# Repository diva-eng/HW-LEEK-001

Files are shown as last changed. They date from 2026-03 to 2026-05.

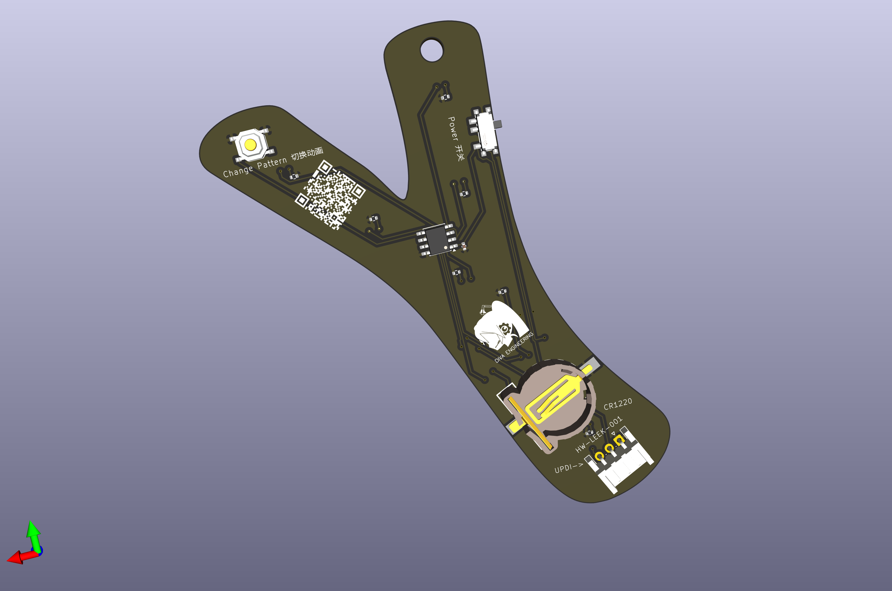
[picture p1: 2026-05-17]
HW-LEEK-001.png

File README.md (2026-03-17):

# Leek PCB Keychain

A small-form-factor PCB keychain shaped like Hatsune Miku's iconic leek, designed as concert swag for Magical Mirai. Features green LEDs at the tip, white LEDs at the base, and multiple user-selectable lighting patterns driven by an ATtiny402.

---

## Features

- Leek-shaped PCB outline with keychain mounting hole
- 5x green LEDs (leek tip) + 2x white LEDs (base)
- 4 lighting patterns selectable via tactile button
- SPDT slide switch for hard power on/off
- CR1220 coin cell powered (~16 hours active runtime)
- Fully assembled by JLCPCB (SMT + THT)

## Hardware

| Comment | Designator | Footprint | LCSC | Quantity |
|---|---|---|---|---|
| ATtiny402-SS | U1 | SOIC-8_3.9x4.9mm_P1.27mm | C2053235 | 1 |
| Battery_Cell | BT1 | BAT-SMD_MY-1220-03 | C964818 | 1 |
| C | C1 | C_0402_1005Metric | C1525 | 1 |
| LED | D6,D7 | LED_0603_1608Metric | C189306 | 2 |
| LED | D4,D5 | LED_0603_1608Metric | C5246833 | 2 |
| LED | D1,D2,D3 | LED_0805_2012Metric | C5355441 | 3 |
| R | R6,R7 | R_0402_1005Metric | C25076 | 2 |
| R | R1,R2,R3,R4,R5 | R_0402_1005Metric | C25104 | 5 |
| ~ | SW3 | SW-TH_K3-1296S-E1 | C128955 | 1 |
| ~ | SW4 | SW-SMD_4P-L5.1-W5.1-P3.70-LS6.5-TL_H1.5 | C318884 | 1 |
| Conn_01x03_Pin | J1 | JST_EH_S3B-EH_1x03_P2.50mm_Horizontal |  | 1 |

See the full design document for complete BOM, resistor values, and wiring details.

## Firmware

Written in Arduino IDE using [megaTinyCore](https://github.com/SpenceKonde/megaTinyCore).

**Board manager URL:**
```
http://drazzy.com/package_drazzy.com_index.json
```

**Board settings:**
- Board: `ATtiny402`
- Clock: Internal 32kHz
- Programmer: SerialUPDI or Microchip SNAP

## Programming

The ATtiny402 is programmed via UPDI using 3 pads on the PCB edge (GND, VCC, UPDI). The cheapest programmer is a CH340 USB-serial adapter with a 1kΩ resistor:

```
USB-Serial TX ── 1kΩ ── UPDI pad
USB-Serial RX ──────── UPDI pad
GND ────────────────── GND pad
```

## LED Patterns

| # | Name | Description |
|---|---|---|
| 1 | Slow Pulse | Both LEDs breathe in and out together |
| 2 | Alternate | Green and white flash in turns |
| 3 | Chase | Green → white → both → off, repeat |
| 4 | Heartbeat | Double-flash then long pause |

Press the pattern button to cycle. The selected pattern is saved to EEPROM and restored on next power-on.

## License

MIT — see [LICENSE](LICENSE)

---

*A [Diva Engineering](https://github.com/diva-eng) project.*

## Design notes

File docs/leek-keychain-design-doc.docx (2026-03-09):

DIVA ENGINEERING

Leek PCB Keychain

Hardware Design Document | Magical Mirai Concert Swag

Document ID | HW-LEEK-001
Version | 1.0
Date | March 2026
Author | Diva Engineering
GitHub | https://github.com/diva-eng
Status | Draft — Ready for PCB Design

# 1. Project Overview

The Leek PCB Keychain is a small-form-factor PCB designed to be distributed as concert swag at Magical Mirai events. Shaped like Hatsune Miku's iconic leek prop, it features green LEDs at the tip and white LEDs at the base, driven by a microcontroller with multiple user-selectable lighting patterns. The device is powered by a coin cell battery and includes a power switch and a pattern selection button.

## 1.1 Design Goals

- Leek-shaped PCB outline, keychain form factor
- Green LEDs at the tip (leek top), white LEDs at the base (cut end)
- 4 stored lighting patterns, selectable via a tactile button
- SPDT slide switch for hard power on/off
- CR1220 coin cell power — small enough for keychain use
- Fully assembled by JLCPCB (SMT + THT)
- Firmware written in Arduino IDE using megaTinyCore

## 1.2 Project References

- Related project: BOKAKA smart PCB card (https://github.com/diva-eng/BOKAKA)
- Related project: diva-card RP2040 dev board (https://github.com/diva-eng/diva-card)
- Org GitHub: https://github.com/diva-eng

# 2. Hardware Specification

## 2.1 Microcontroller — ATtiny402

The ATtiny402 in SOT-23-8 is selected as the MCU. It is a Microchip AVR 0-series device with sufficient I/O for this application, native PWM for LED fading, and extremely low sleep current. It is supported by JLCPCB assembly and programmable via UPDI using Arduino IDE with megaTinyCore.

Parameter | Value
Package | SOT-23-8
Flash | 4KB
SRAM | 256 bytes
EEPROM | 128 bytes
Operating Voltage | 1.8V – 5.5V
Active Current @ 1MHz | ~0.8mA
Active Current @ 32kHz | ~100µA
Power-down Sleep | ~0.1µA
PWM channels | 2 (TCA0)
Programming Interface | UPDI (single wire)
LCSC Part | C440337

## 2.2 Pin Allocation

Physical Pin | Port | Arduino Pin (megaTinyCore) | Function
1 | VCC | — | Power supply
2 | PA6 | 1 | Green LED group output
3 | PA7 | 2 | White LED group output
4 | PA1 | 4 | UPDI programming
5 | PA2 | 3 | Pattern select button input
6 | PA3 | — | Spare / future use
7 | GND | — | Ground
8 | PA0 | — | RESET (not used)

## 2.3 Power — CR1220 Coin Cell

The CR1220 is chosen as the primary power source. It offers a good balance of small physical size and sufficient capacity for concert use. Since the device includes a hard power switch, battery life in active use is the only relevant metric.

Parameter | Value
Chemistry | Lithium manganese dioxide
Diameter | 12mm
Thickness | 2.0mm
Nominal Voltage | 3V
Capacity | ~35mAh
Estimated active runtime | ~16 hours @ 2.1mA total draw
Concerts covered | 5+ at 3 hours each
LCSC Holder Part | C70377

## 2.4 LED Specification

Green LEDs (Leek Tip — 4x)

Parameter | Value
Color | Green
Package | 0402 SMD
Forward Voltage (Vf) | ~2.1 – 2.3V
Target current per LED | 2mA
Series resistor | 390Ω
LCSC Part | C2297 (verify Vf in datasheet)
Qty | 4

White LEDs (Leek Base — 2x)

White LEDs have a forward voltage near the coin cell supply voltage. Use low-Vf white LEDs (Vf ≤ 2.8V) to ensure reliable operation.

Parameter | Value
Color | White (low Vf)
Package | 0402 SMD
Forward Voltage (Vf) | ≤ 2.8V (verify before ordering)
Target current per LED | 2mA
Series resistor | 68Ω
LCSC Part | C2290 (verify Vf ≤ 2.8V in datasheet)
Qty | 2

## 2.5 Passive Components

Ref | Component | Value | Package | LCSC Part | Qty
C1 | Bypass capacitor | 100nF 10V | 0402 | C307331 | 1
R1–R4 | Green LED resistors | 390Ω | 0402 | C105872 | 4
R5–R6 | White LED resistors | 68Ω | 0402 | C105854 | 2

## 2.6 Switches

Ref | Component | Type | Package | LCSC Part | Qty
SW1 | Power switch | SPDT slide | SMD | C431540 | 1
SW2 | Pattern select | Tactile push button | 3x4mm SMD | C455280 | 1

# 3. Full Bill of Materials

All parts are sourced from LCSC and suitable for JLCPCB SMT + THT assembly. Verify all LCSC part numbers and datasheets before placing the order, especially LED Vf values.

Ref | Component | Value / Part | Package | LCSC Part | Qty | Assembly
U1 | MCU | ATtiny402 | SOT-23-8 | C440337 | 1 | SMT
C1 | Bypass Cap | 100nF 10V | 0402 | C307331 | 1 | SMT
R1–R4 | Resistor | 390Ω | 0402 | C105872 | 4 | SMT
R5–R6 | Resistor | 68Ω | 0402 | C105854 | 2 | SMT
D1–D4 | Green LED | Low Vf Green | 0402 | C2297 | 4 | SMT
D5–D6 | White LED | Low Vf White ≤2.8V | 0402 | C2290 | 2 | SMT
SW1 | Power Switch | SPDT Slide | SMD | C431540 | 1 | SMT
SW2 | Pattern Button | Tactile 3x4mm | SMD | C455280 | 1 | SMT
BT1 | Battery Holder | CR1220 | THT | C70377 | 1 | THT
J1 | UPDI Header | 3-pin 2.54mm | THT | C49257 | 1 | THT

Note: J1 (UPDI header) can be replaced with 3 exposed edge pads for pogo-pin programming after the first batch is validated, removing the need for a physical header.

# 4. Circuit Description

## 4.1 Power Path

The CR1220 positive terminal connects through SW1 (SPDT slide switch) to the VCC rail. The negative terminal connects directly to GND. C1 (100nF ceramic) is placed as close as possible to the ATtiny402 VCC pin to decouple supply noise.

CR1220(+) ── SW1 (slide) ── VCC rail ── ATtiny402 VCC

CR1220(-) ──────────────── GND

C1 (100nF) between VCC and GND, placed near U1

## 4.2 LED Wiring

Each LED has an individual series resistor. All LEDs in a group share the same MCU output pin. Cathodes connect to GND.

ATtiny402 PA6 ──┬── R1 (390Ω) ── D1 (Green) ── GND

├── R2 (390Ω) ── D2 (Green) ── GND

├── R3 (390Ω) ── D3 (Green) ── GND

└── R4 (390Ω) ── D4 (Green) ── GND

ATtiny402 PA7 ──┬── R5 (68Ω) ── D5 (White) ── GND

└── R6 (68Ω) ── D6 (White) ── GND

## 4.3 Pattern Select Button

SW2 connects PA2 to GND. The ATtiny402 internal pullup is enabled in firmware, so no external pullup resistor is required. Button press pulls PA2 low, triggering a pattern change with software debounce.

ATtiny402 PA2 ── SW2 ── GND

(Internal pullup enabled in firmware — no external resistor needed)

## 4.4 UPDI Programming Header

J1 is a 3-pin 2.54mm THT header exposing GND, VCC, and UPDI (PA1) for in-system programming. Place on the board edge for pogo-pin access.

J1 Pin 1: GND

J1 Pin 2: VCC

J1 Pin 3: UPDI (PA1)

# 5. LED Patterns

Four patterns are stored in firmware. The active pattern is saved to EEPROM so it persists across power cycles. Patterns are cycled by pressing SW2 (short press).

# | Name | Green (PA6) | White (PA7) | Description

1 | Slow Pulse | PWM breathe | PWM breathe | Both LEDs fade in and out together slowly
2 | Alternate | Flash on | Flash off (inverse) | Green and white take turns flashing
3 | Chase | On → Off → Both | Off → On → Both | Sequential: green, white, both, off
4 | Heartbeat | Double-flash + pause | Double-flash + pause | Quick double-flash then a long pause

PWM fading uses the ATtiny402 hardware TCA0 peripheral. No bit-banging is required. The 32kHz internal oscillator is sufficient for smooth visible fading.

# 6. Firmware

## 6.1 Toolchain

Tool | Version / Details
IDE | Arduino IDE 2.x
Board Package | megaTinyCore by Spence Konde
Board Manager URL | http://drazzy.com/package_drazzy.com_index.json
Board Selection | ATtiny402
Clock | Internal 32kHz (sufficient for LED PWM)
Programmer | SerialUPDI or Microchip SNAP

## 6.2 Firmware Structure

#include <Arduino.h>

#include <EEPROM.h>

#define PIN_GREEN PIN_PA6

#define PIN_WHITE PIN_PA7

#define PIN_BUTTON PIN_PA2

#define NUM_PATTERNS 4

uint8_t currentPattern = 0;

void setup() {

pinMode(PIN_GREEN, OUTPUT);

pinMode(PIN_WHITE, OUTPUT);

pinMode(PIN_BUTTON, INPUT_PULLUP);

currentPattern = EEPROM.read(0) % NUM_PATTERNS;

}

void loop() {

if (digitalRead(PIN_BUTTON) == LOW) {

delay(50); // debounce

if (digitalRead(PIN_BUTTON) == LOW) {

currentPattern = (currentPattern + 1) % NUM_PATTERNS;

EEPROM.update(0, currentPattern);

while (digitalRead(PIN_BUTTON) == LOW);

}

}

switch (currentPattern) {

case 0: patternSlowPulse(); break;

case 1: patternAlternate(); break;

case 2: patternChase(); break;

case 3: patternHeartbeat(); break;

}

}

## 6.3 EEPROM Usage

The last active pattern index is stored at EEPROM address 0 using EEPROM.update() (only writes if value changed, preserving EEPROM write cycle life). On boot, this value is read and restored.

# 7. Programming Setup

## 7.1 SerialUPDI Programmer (Recommended)

A CH340 or CP2102 USB-to-serial adapter with a 1kΩ resistor bodge is sufficient for programming. This is the lowest-cost option and fully supported by megaTinyCore.

USB-Serial TX ── 1kΩ ── UPDI pin (J1 Pin 3)

USB-Serial RX ──────── UPDI pin (J1 Pin 3)

GND ────────────────── GND (J1 Pin 1)

(Power the board from the coin cell during programming)

## 7.2 Microchip SNAP (Alternative)

The Microchip SNAP (~$35 USD) is the official programmer and supports UPDI natively. Recommended if this project leads to further ATtiny development at Diva Engineering.

## 7.3 Batch Programming Jig

For production batches, expose 3 pads on the PCB edge (GND, VCC, UPDI) and use a 3D-printed pogo-pin jig to program boards without soldering headers. Each board programs in approximately 5 seconds.

Pad | Signal | Notes
J1 Pin 1 | GND | Connect to programmer GND
J1 Pin 2 | VCC | Monitor only — power from coin cell
J1 Pin 3 | UPDI (PA1) | Single-wire programming data

# 8. PCB Design Notes

## 8.1 Form Factor

- Leek-shaped outline — elongated with a bulbous bottom (white LEDs) tapering to a tip (green LEDs)
- Keychain hole: 3mm diameter, reinforced with annular copper ring, placed at the base
- Target max dimensions: ~30mm length × 10mm width
- PCB thickness: 1.6mm standard
- Silkscreen: Include Diva Engineering logo and Magical Mirai year on back

## 8.2 Component Placement

- U1 (ATtiny402): Center of board, away from LEDs to avoid thermal interference
- C1 (100nF bypass): As close as possible to U1 VCC pin
- D1–D4 (Green LEDs): Along the upper PCB outline (leek tip region)
- D5–D6 (White LEDs): Along the lower PCB outline (base region)
- SW1 (Slide switch): Bottom edge, accessible with thumb
- SW2 (Tactile button): Front face, easy to press
- BT1 (CR1220 holder): Back of PCB, centered
- J1 (UPDI header): PCB edge, or replace with 3 exposed pads for pogo programming

## 8.3 Design Rules for JLCPCB

Parameter | Value
Min trace width | 0.127mm (5mil)
Min clearance | 0.127mm (5mil)
Min drill size | 0.3mm
Copper layers | 2 (F.Cu, B.Cu)
Surface finish | HASL or ENIG (ENIG recommended for 0402)
Solder mask | Green (or custom color — white for leek aesthetic)
Silkscreen | White (F.Cu side)

## 8.4 JLCPCB Assembly Notes

- All SMT components (U1, C1, R1–R6, D1–D6, SW1, SW2) eligible for Economic PCBA
- THT components (BT1, J1) eligible for THT assembly — include in same order
- U1 (ATtiny402) ships blank from JLCPCB — firmware must be flashed after delivery
- Mark component orientation clearly on silkscreen, especially D1–D6 LED polarity
- Confirm CR1220 holder footprint matches C70377 before submitting Gerbers

# 9. Power Budget

The device is switched off between uses. Battery life is calculated for active (on) use only.

Component | Current Draw | Notes
ATtiny402 @ 32kHz | ~0.1mA | Running pattern logic
Green LEDs × 4 @ 2mA each | ~8mA peak | Dependent on PWM duty cycle
White LEDs × 2 @ 2mA each | ~4mA peak | Dependent on PWM duty cycle
Total (all on, peak) | ~12.1mA | Worst case, all LEDs at full brightness
Total (typical active) | ~2–4mA | Average with PWM patterns at ~25% duty

Scenario | Current | CR1220 (35mAh) Life
Peak (all LEDs fully on) | ~12.1mA | ~2.9 hours
Typical (PWM patterns) | ~2–4mA | ~9–17 hours
Conservative (dim + slow) | ~1mA | ~35 hours

A 3-hour concert is well within range under any realistic usage pattern. Upgrading to CR1632 (120mAh, 16mm diameter) would provide 3–4× the runtime with minimal size increase.

# 10. Open Items & Pre-Order Checklist

# | Item | Status | Owner

1 | Verify white LED Vf ≤ 2.8V on LCSC C2290 datasheet | Open | Hardware
2 | Verify green LED Vf ~2.1–2.3V on LCSC C2297 datasheet | Open | Hardware
3 | Confirm CR1220 holder C70377 footprint dimensions | Open | Hardware
4 | Confirm slide switch C431540 footprint | Open | Hardware
5 | Design PCB outline (leek shape) in KiCad | Open | Hardware
6 | Confirm JLCPCB THT assembly availability for BT1 | Open | Manufacturing
7 | Write and test all 4 LED pattern functions in firmware | Open | Firmware
8 | Test EEPROM pattern persistence across power cycles | Open | Firmware
9 | Build SerialUPDI programmer dongle (CH340 + 1kΩ) | Open | Tools
10 | Order 3–5 prototype boards before full batch | Recommended | Project

# 11. Revision History

Version | Date | Author | Changes
1.0 | March 2026 | Diva Engineering | Initial design document

Confidential — Diva Engineering Page 1

Diva Engineering | Leek PCB Keychain HW-LEEK-001

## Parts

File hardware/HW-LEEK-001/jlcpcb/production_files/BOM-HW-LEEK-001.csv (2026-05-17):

Comment | Designator | Footprint | LCSC | Quantity
ATtiny402-SS | U1 | SOIC-8_3.9x4.9mm_P1.27mm | C2053235 | 1
Battery_Cell | BT1 | BAT-SMD_CR1220-2ZX | C969906 | 1
C | C1 | C_0402_1005Metric | C1525 | 1
LED | D1,D2,D3,D4,D5 | LED_0805_2012Metric | C5569446 | 5
LED | D6,D7 | LED_0805_2012Metric | C7280948 | 2
R | R6,R7 | R_0402_1005Metric | C25092 | 2
R | R1,R2,R3,R4,R5 | R_0402_1005Metric | C25104 | 5
~ | SW3 | SW-TH_K3-1296S-E1 | C128955 | 1
~ | SW4 | SW-SMD_4P-L5.1-W5.1-P3.70-LS6.5-TL_H1.5 | C318884 | 1
Conn_01x03_Pin | J1 | JST_EH_S3B-EH_1x03_P2.50mm_Horizontal |  | 1

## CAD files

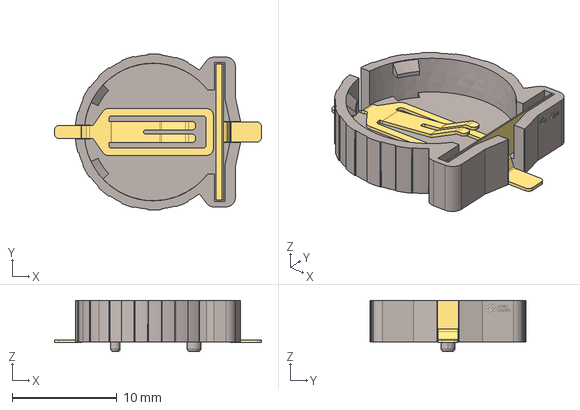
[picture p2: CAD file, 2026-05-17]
hardware/HW-LEEK-001/EASYEDA_MODELS/BAT-SMD_CR1220-2.step
19.8 x 14.9 x 4.90 mm

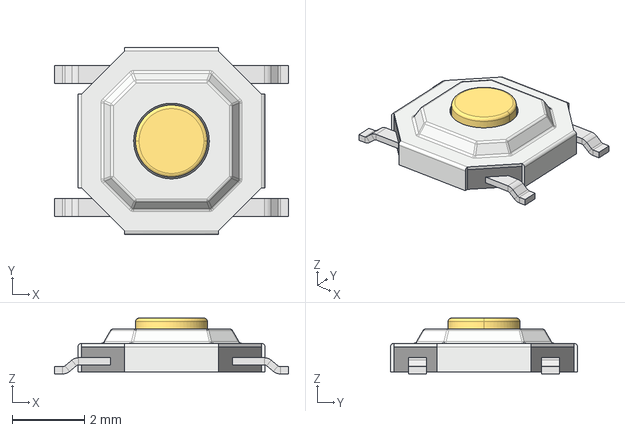
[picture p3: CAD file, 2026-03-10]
hardware/HW-LEEK-001/EASYEDA_MODELS/SW-SMD_4P-L5.1-W5.1-P3.70-LS6.5-TL_H1.5.step
6.50 x 5.20 x 1.55 mm

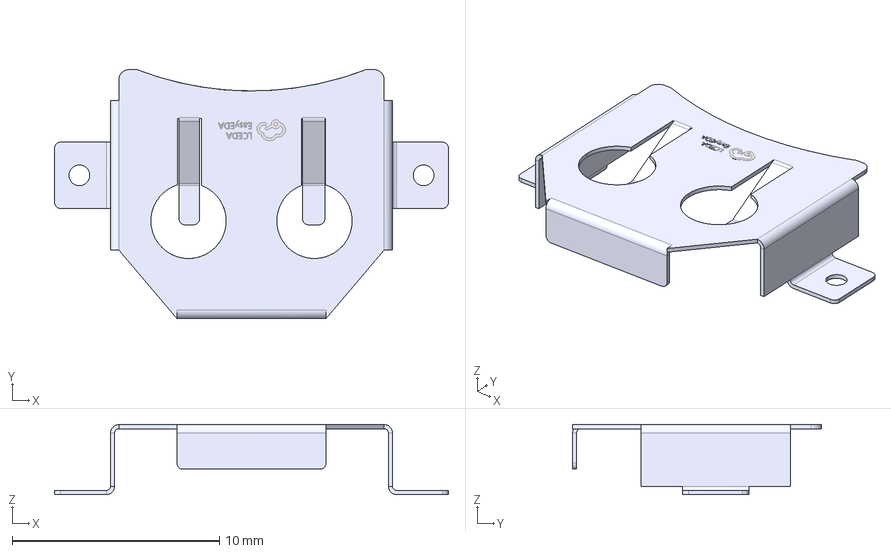
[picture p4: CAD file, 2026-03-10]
hardware/HW-LEEK-001/EASYEDA_MODELS/BAT-SMD_MY-1220-03.step
19.0 x 12.0 x 3.38 mm

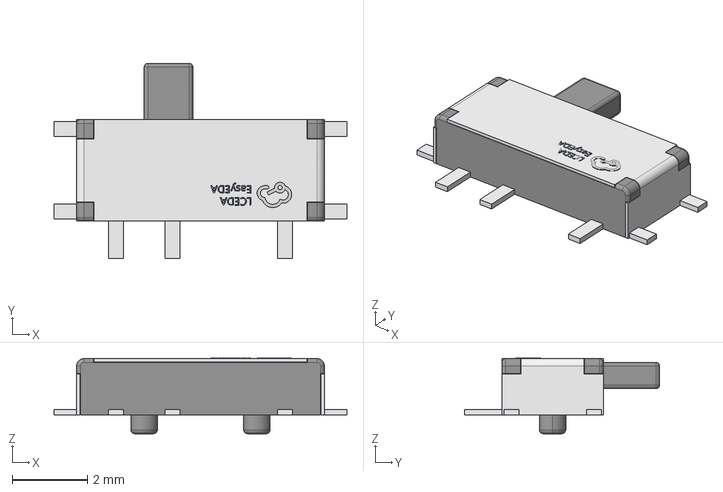
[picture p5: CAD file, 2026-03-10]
hardware/HW-LEEK-001/EASYEDA_MODELS/SW-SMD_3P-L6.6-W2.7-LS7.8-P1.50.step
7.80 x 5.20 x 2.01 mm

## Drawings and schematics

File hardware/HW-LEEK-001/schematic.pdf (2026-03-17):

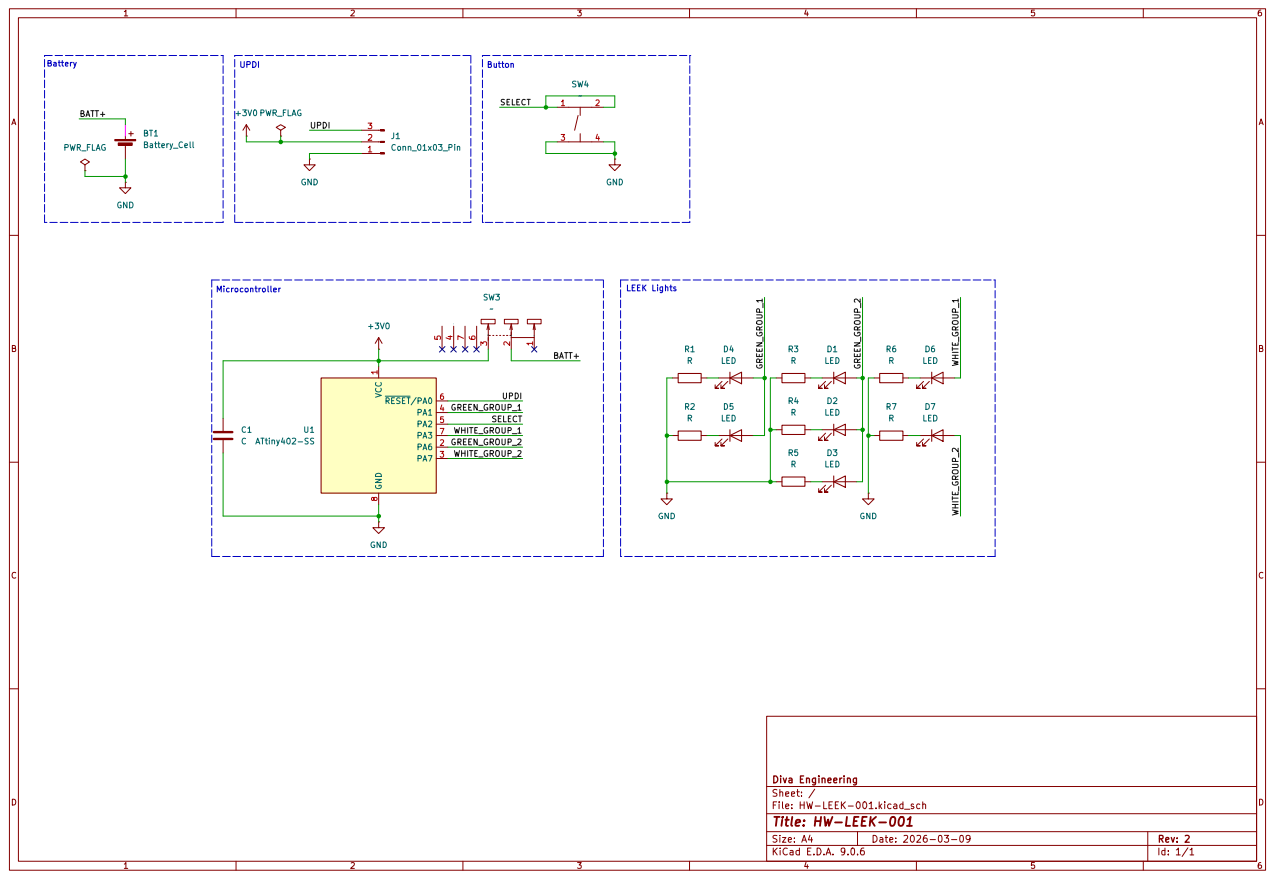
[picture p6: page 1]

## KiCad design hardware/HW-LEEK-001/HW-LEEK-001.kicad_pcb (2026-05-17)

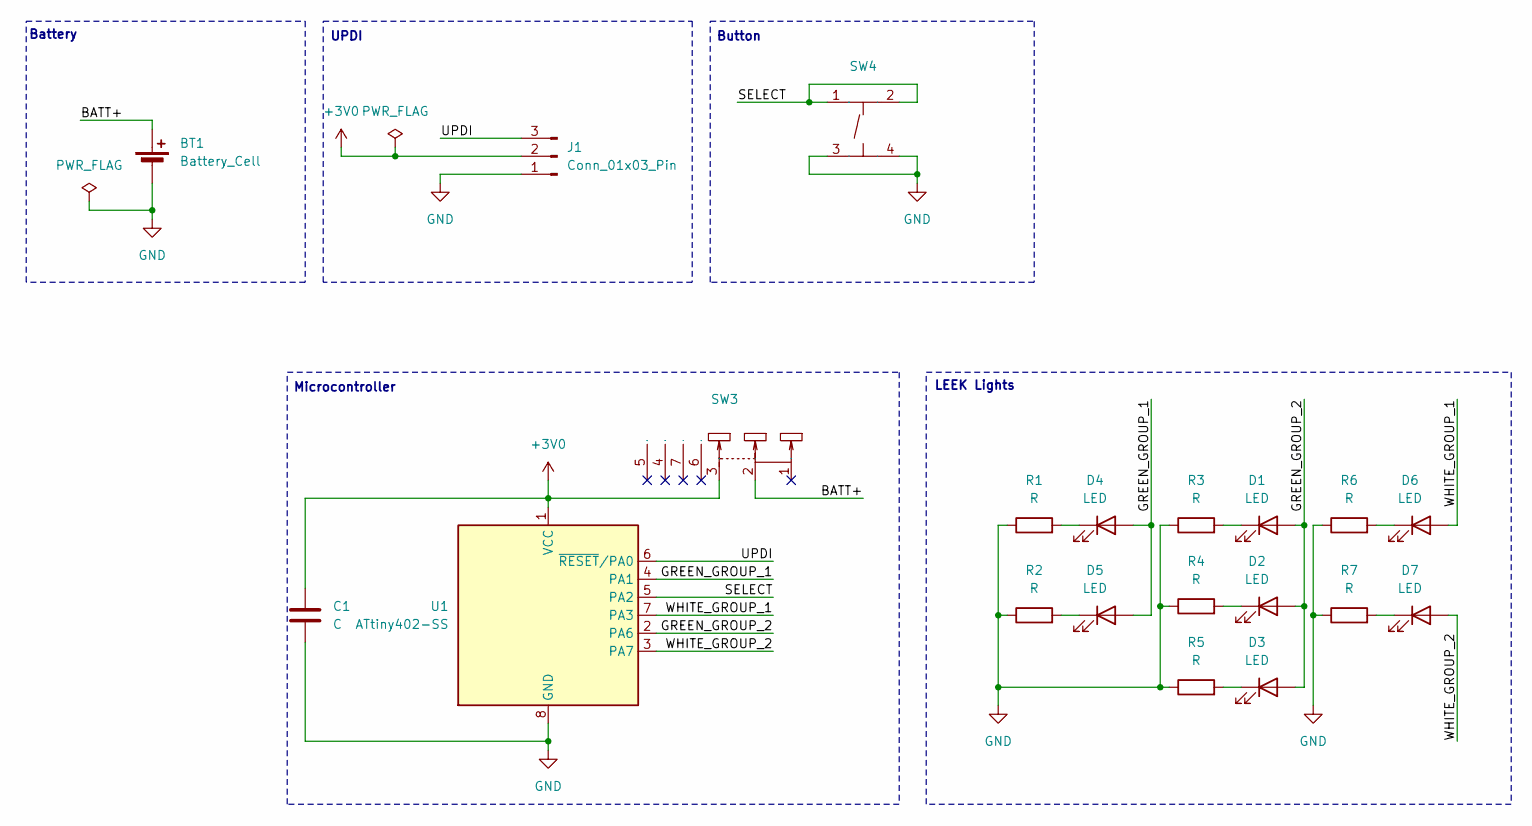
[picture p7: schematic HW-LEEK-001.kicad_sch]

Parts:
BT1: Battery_Cell; BAT-SMD_CR1220-2ZX; LCSC C964818
C1: C; C_0402_1005Metric; LCSC C1525
D1, D2, D3: LED; LED_0805_2012Metric; LCSC C5355441
D4, D5: LED; LED_0805_2012Metric; LCSC C5246833
D6, D7: LED; LED_0805_2012Metric; LCSC C189306
J1: Conn_01x03_Pin; JST_EH_S3B-EH_1x03_P2.50mm_Horizontal
R1, R2, R3, R4, R5: R; R_0402_1005Metric; LCSC C25104
R6, R7: R; R_0402_1005Metric; LCSC C25076
SW3: SW-TH_K3-1296S-E1; Manufacturer Part K3-1296S-E1; LCSC Part Name 卧贴双档 滑动开关
SW4: SW-SMD_4P-L5.1-W5.1-P3.70-LS6.5-TL_H1.5; Manufacturer Part TS-1187A-B-A-B; LCSC Part Name 5.1*5.1*1.5mm 立贴 轻触开关
U1: ATtiny402-SS; SOIC-8_3.9x4.9mm_P1.27mm; LCSC C2053235

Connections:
+3V0: C1.1, J1.2, SW3.3, U1.1 (VCC)
/BATT+: BT1.1 (+), SW3.2
/GREEN_GROUP_1: D4.2 (A), D5.2 (A), U1.4 (PA1)
/GREEN_GROUP_2: D1.2 (A), D2.2 (A), D3.2 (A), U1.2 (PA6)
/SELECT: SW4.1 (A), SW4.2 (B), U1.5 (PA2)
/UPDI: J1.3, U1.6 (~RESET/PA0)
/WHITE_GROUP_1: D6.2 (A), U1.7 (PA3)
/WHITE_GROUP_2: D7.2 (A), U1.3 (PA7)
GND: BT1.2 (-), C1.2, J1.1, R1.1, R2.1, R3.1, R4.1, R5.1, R6.1, R7.1, SW4.3 (C), SW4.4 (D), U1.8 (GND)
unnamed: D1.1 (K), R3.2
unnamed: D2.1 (K), R4.2
unnamed: D3.1 (K), R5.2
unnamed: D4.1 (K), R1.2
unnamed: D5.1 (K), R2.2
unnamed: D6.1 (K), R6.2
unnamed: D7.1 (K), R7.2

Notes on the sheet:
UPDI
Battery
LEEK Lights
Button
Microcontroller

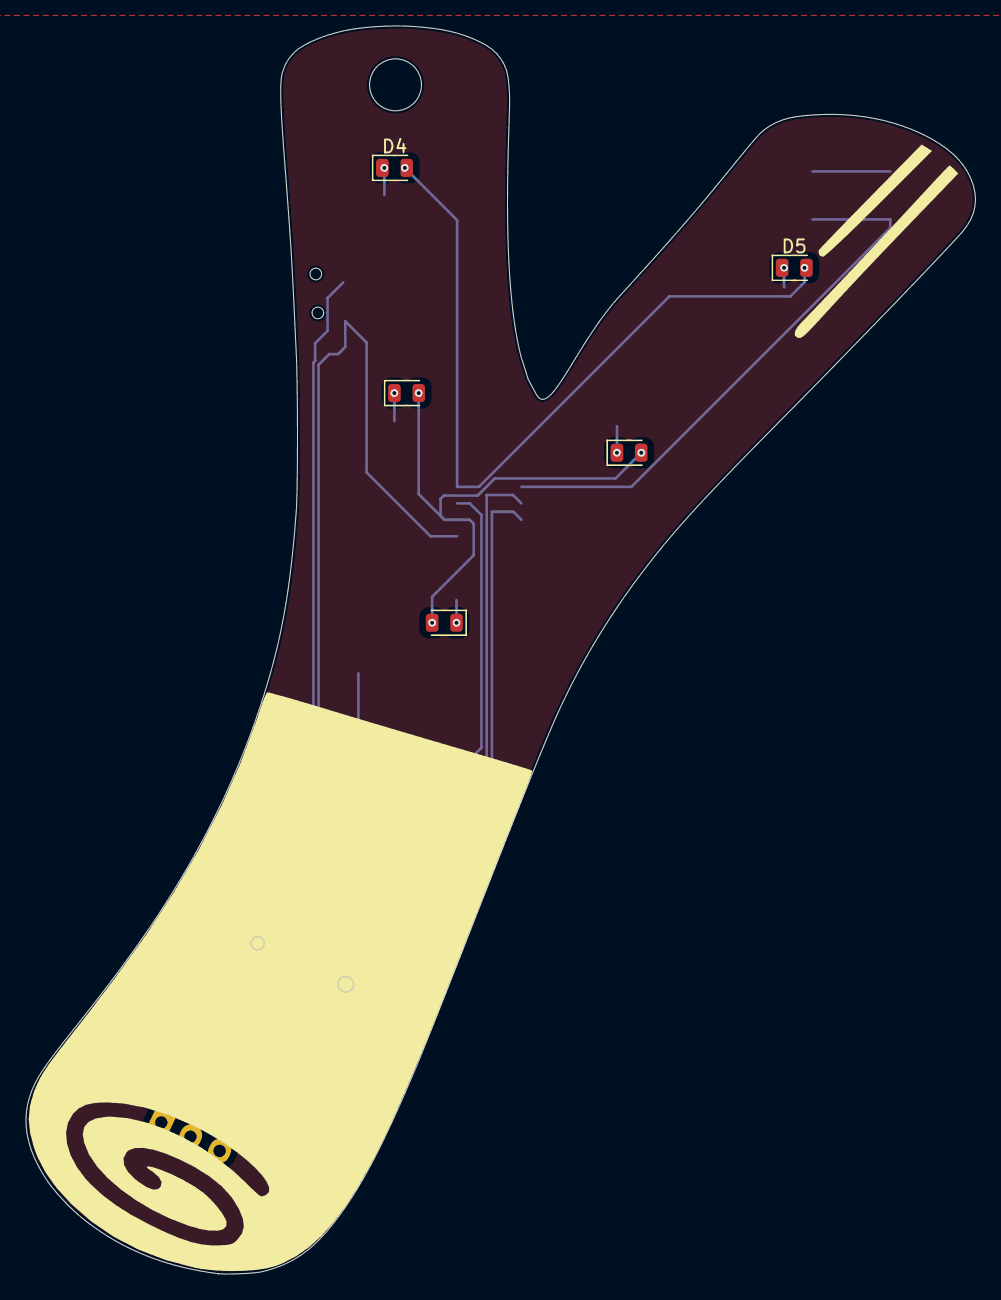
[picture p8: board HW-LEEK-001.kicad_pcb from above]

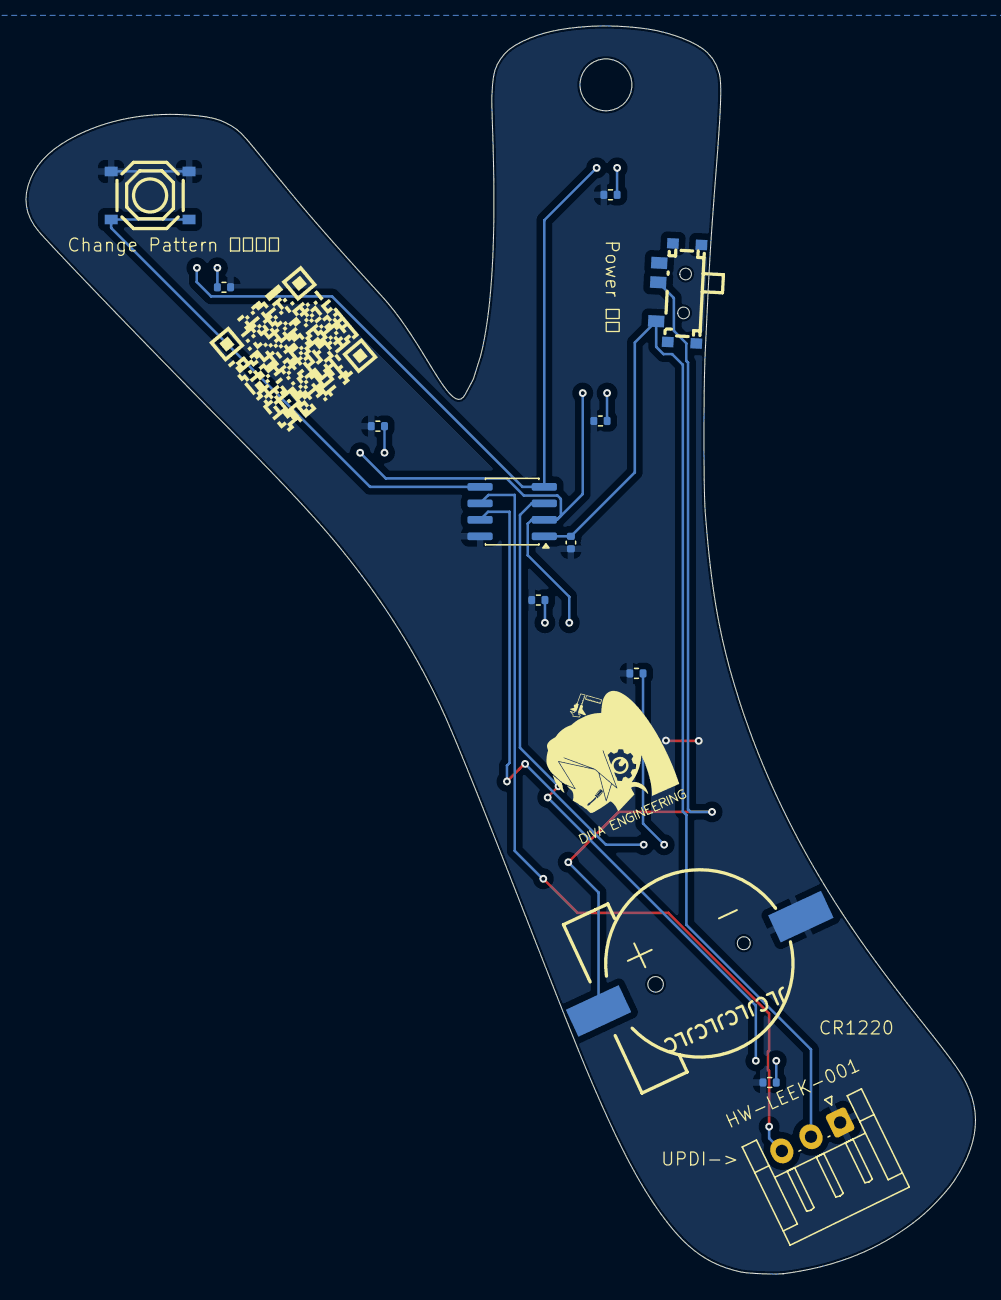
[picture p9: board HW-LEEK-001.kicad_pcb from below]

Board: 2 copper layers, 73.2 x 96.2 mm, 21 parts (13 on the bottom side), 16 nets.

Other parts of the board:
svg2mod: G***; leek

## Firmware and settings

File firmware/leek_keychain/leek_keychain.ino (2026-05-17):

/**
 * Leek PCB Keychain Firmware
 * Diva Engineering — https://github.com/diva-eng
 *
 * Hardware: ATtiny402-SS (SOT-23-8) — MANUFACTURED PCB
 * Toolchain: Arduino IDE + megaTinyCore
 * Board manager: http://drazzy.com/package_drazzy.com_index.json
 * Board: ATtiny402 | Clock: Internal 5MHz | Programmer: SerialUPDI / SNAP
 *
 * ─────────────────────────────────────────────────────────────────────────────
 * PIN MAPPING (final PCB, from schematic)
 * ─────────────────────────────────────────────────────────────────────────────
 *
 *   PA0 / RESET  —  UPDI (programming only, do not use in firmware)
 *   PA1          —  GREEN_GROUP_1  — leek TIP        (2× green, topmost)
 *   PA2          —  SELECT button  — active LOW, internal pullup
 *   PA3          —  WHITE_GROUP_1  — below green group 2
 *   PA6          —  GREEN_GROUP_2  — 3× green, below tip
 *   PA7          —  WHITE_GROUP_2  — bottommost single LED
 *
 * ─────────────────────────────────────────────────────────────────────────────
 * PHYSICAL LED ORDER top → bottom
 * ─────────────────────────────────────────────────────────────────────────────
 *
 *   [1] GREEN_GROUP_1  PA1  — tip         (2× green)
 *   [2] GREEN_GROUP_2  PA6  — upper stalk (3× green)
 *   [3] WHITE_GROUP_1  PA3  — lower stalk (1× white)
 *   [4] WHITE_GROUP_2  PA7  — base        (1× white)
 *
 * ─────────────────────────────────────────────────────────────────────────────
 * ADDING A NEW PATTERN
 * ─────────────────────────────────────────────────────────────────────────────
 *
 * 1. Choose a category: WAVE, BREATH, or BLINK (or add a new category label).
 *
 * 2. Write your pattern function following this signature:
 *      void myPattern(bool firstRun);
 *    - firstRun is true on the first call after switching to this pattern.
 *      Use it to reset any static state inside your function.
 *    - NEVER use delay() inside a pattern. Use the wait() helper instead.
 *    - Use the LED helpers: setTip(), setUpperStalk(), setLowerStalk(),
 *      setBase(), setAllGreen(), setAllWhite(), setAll(), allOff().
 *    - Use sineWave(phase, lo, hi) for smooth fading.
 *
 * 3. Register it in the PATTERNS[] table at the bottom of this file:
 *      { CAT_WAVE,  myPattern,  "My Pattern" }
 *
 * NUM_PATTERNS is calculated automatically. Nothing else needs changing.
 * ─────────────────────────────────────────────────────────────────────────────
 */

#include <Arduino.h>
#include <EEPROM.h>

// ═══════════════════════════════════════════════════════════════════════════════
// HARDWARE PIN DEFINITIONS
// ═══════════════════════════════════════════════════════════════════════════════

#define PIN_TIP           PIN_PA1   // GREEN_GROUP_1 — leek tip       (2× green)
#define PIN_UPPER_STALK   PIN_PA6   // GREEN_GROUP_2 — upper stalk    (3× green)
#define PIN_LOWER_STALK   PIN_PA3   // WHITE_GROUP_1 — lower stalk    (1× white)
#define PIN_BASE          PIN_PA7   // WHITE_GROUP_2 — base           (1× white)
#define PIN_BUTTON        PIN_PA2   // SELECT button — active LOW

// ═══════════════════════════════════════════════════════════════════════════════
// CONFIGURATION
// ═══════════════════════════════════════════════════════════════════════════════

#define EEPROM_PATTERN_ADDR   0       // EEPROM byte address for pattern persistence
#define DEBOUNCE_MS           50      // Button debounce window (ms)
#define PWM_MAX               255     // Full brightness PWM value
#define PWM_DIM               30      // Dim glow level used by some patterns

// ═══════════════════════════════════════════════════════════════════════════════
// PATTERN CATEGORIES
// Used for grouping only — no functional effect, helps readability.
// ═══════════════════════════════════════════════════════════════════════════════

#define CAT_WAVE    0
#define CAT_BREATH  1
#define CAT_BLINK   2

// ═══════════════════════════════════════════════════════════════════════════════
// PATTERN TYPE
// ═══════════════════════════════════════════════════════════════════════════════

typedef void (*PatternFn)(bool firstRun);

struct Pattern {
  uint8_t     category;   // CAT_WAVE / CAT_BREATH / CAT_BLINK
  PatternFn   fn;
  const char* name;
};

// ═══════════════════════════════════════════════════════════════════════════════
// LED HELPERS
// Named after physical position on the leek for readability in pattern code.
// ═══════════════════════════════════════════════════════════════════════════════

// Individual groups — top to bottom
inline void setTip        (uint8_t v) { analogWrite(PIN_TIP,          v); }
inline void setUpperStalk (uint8_t v) { analogWrite(PIN_UPPER_STALK,  v); }
inline void setLowerStalk (uint8_t v) { analogWrite(PIN_LOWER_STALK,  v); }
inline void setBase       (uint8_t v) { analogWrite(PIN_BASE,         v); }

// Convenience group setters
inline void setAllGreen(uint8_t v)    { setTip(v);  setUpperStalk(v); }
inline void setAllWhite(uint8_t v)    { setLowerStalk(v); setBase(v); }
inline void setAll(uint8_t v)         { setAllGreen(v); setAllWhite(v); }
inline void allOff()                  { setAll(0); }

// Set all four groups individually in one call (top → bottom order)
inline void setGroups(uint8_t tip, uint8_t upper, uint8_t lower, uint8_t base) {
  setTip(tip);
  setUpperStalk(upper);
  setLowerStalk(lower);
  setBase(base);
}

// ═══════════════════════════════════════════════════════════════════════════════
// TIMING HELPER
// ═══════════════════════════════════════════════════════════════════════════════

/**
 * Non-blocking wait. Returns true when 'duration' ms have passed since 'since'.
 *
 * Usage:
 *   static uint32_t t = 0;
 *   if (wait(t, 200)) { t = millis(); doThing(); }
 */
inline bool wait(uint32_t since, uint32_t duration) {
  return (millis() - since) >= duration;
}

// ═══════════════════════════════════════════════════════════════════════════════
// WAVEFORM HELPER
// ═══════════════════════════════════════════════════════════════════════════════

/**
 * Fast triangle-wave approximation of a sine curve (avoids sin() on AVR).
 * phase : 0–255 = one full cycle
 * lo    : minimum output brightness  (default 0)
 * hi    : maximum output brightness  (default 255)
 */
uint8_t sineWave(uint8_t phase, uint8_t lo = 0, uint8_t hi = PWM_MAX) {
  uint8_t tri = (phase < 128) ? (phase * 2) : (255 - (phase - 128) * 2);
  return lo + (uint8_t)(((uint16_t)(hi - lo) * tri) / 255);
}

// ═══════════════════════════════════════════════════════════════════════════════
// ── WAVE PATTERNS ─────────────────────────────────────────────────────────────
// Groups light up in sequence top → bottom, like energy running down the leek.
// ═══════════════════════════════════════════════════════════════════════════════

/**
 * Wave — Slow Cascade Down
 * Each group fades in one at a time, tip → base, then all fade out together.
 * Gentle, meditative. Good for low-key moments.
 * Step hold: 350ms per group, 700ms all-on, 400ms off, 300ms pause.
 */
void waveSlowCascade(bool firstRun) {
  static uint32_t t    = 0;
  static uint8_t  step = 0;

  //                         tip    upper  lower  base   hold(ms)
  static const uint16_t dur[] = { 350, 350, 350, 350, 700, 400, 300 };

  if (firstRun) { step = 0; t = millis(); allOff(); }

  if (wait(t, dur[step])) {
    t = millis();
    step = (step + 1) % 7;
    switch (step) {
      case 0: allOff();                                                    break;
      case 1: setGroups(PWM_MAX, 0,       0,       0);                    break;
      case 2: setGroups(PWM_MAX, PWM_MAX, 0,       0);                    break;
      case 3: setGroups(PWM_MAX, PWM_MAX, PWM_MAX, 0);                    break;
      case 4: setAll(PWM_MAX);                                             break;
      case 5: allOff();                                                    break;
      case 6: /* pause before repeat */                                    break;
    }
  }
}

/**
 * Wave — Fast Pulse Up
 * A quick flash travels bottom → tip rapidly, like a spark running up the leek.
 * Each group on for 120ms with a brief off gap between runs.
 */
void wavePulseUp(bool firstRun) {
  static uint32_t t    = 0;
  static uint8_t  step = 0;

  // Steps: base → lower → upper → tip → off gap
  static const uint16_t dur[] = { 120, 120, 120, 120, 250 };

  if (firstRun) { step = 0; t = millis(); allOff(); }

  if (wait(t, dur[step])) {
    t = millis();
    step = (step + 1) % 5;
    allOff();
    switch (step) {
      case 0: setBase(PWM_MAX);        break;
      case 1: setLowerStalk(PWM_MAX);  break;
      case 2: setUpperStalk(PWM_MAX);  break;
      case 3: setTip(PWM_MAX);         break;
      case 4: /* off gap */            break;
    }
  }
}

/**
 * Wave — Ripple
 * Groups light in overlapping sequence so the transition looks fluid.
 * Uses PWM phases offset by 64 steps (quarter cycle) between groups.
 * All groups active simultaneously but at different phases.
 */
void waveRipple(bool firstRun) {
  static uint32_t t     = 0;
  static uint8_t  phase = 0;

  if (firstRun) { phase = 0; t = millis(); }

  if (wait(t, 14)) {
    t = millis();
    phase++;
    // Each group is offset by 64 (quarter cycle), tip leads
    setTip        (sineWave((uint8_t)(phase),        8, PWM_MAX));
    setUpperStalk (sineWave((uint8_t)(phase + 64),   8, PWM_MAX));
    setLowerStalk (sineWave((uint8_t)(phase + 128),  8, PWM_MAX));
    setBase       (sineWave((uint8_t)(phase + 192),  8, PWM_MAX));
  }
}

// ═══════════════════════════════════════════════════════════════════════════════
// ── BREATH PATTERNS ───────────────────────────────────────────────────────────
// Smooth PWM fading. Easy on the eyes for sustained watching.
// ═══════════════════════════════════════════════════════════════════════════════

/**
 * Breath — All Together
 * Every LED group breathes in and out in sync.
 * Full cycle ~3 seconds. Most calming pattern.
 */
void breathAll(bool firstRun) {
  static uint32_t t     = 0;
  static uint8_t  phase = 0;

  if (firstRun) { phase = 0; t = millis(); }

  if (wait(t, 12)) {
    t = millis();
    phase++;
    setAll(sineWave(phase, 4, PWM_MAX));
  }
}

/**
 * Breath — Green / White Crossfade
 * Green groups and white groups breathe opposite each other.
 * As greens brighten, whites dim, and vice versa.
 */
void breathCrossfade(bool firstRun) {
  static uint32_t t     = 0;
  static uint8_t  phase = 0;

  if (firstRun) { phase = 0; t = millis(); }

  if (wait(t, 10)) {
    t = millis();
    phase++;
    setAllGreen(sineWave(phase,             4, PWM_MAX));
    setAllWhite(sineWave((uint8_t)(phase + 128), 4, PWM_MAX));
  }
}

/**
 * Breath — Tip Focus
 * Tip pulses fully while the rest of the leek holds a soft constant dim glow.
 * Draws the eye to the top of the leek.
 */
void breathTipFocus(bool firstRun) {
  static uint32_t t     = 0;
  static uint8_t  phase = 0;

  if (firstRun) { phase = 0; t = millis(); }

  if (wait(t, 9)) {
    t = millis();
    phase++;
    setTip(sineWave(phase, 10, PWM_MAX));
    setUpperStalk(PWM_DIM);
    setLowerStalk(PWM_DIM / 2);
    setBase(PWM_DIM / 2);
  }
}

// ═══════════════════════════════════════════════════════════════════════════════
// ── BLINK PATTERNS ────────────────────────────────────────────────────────────
// Hard on/off transitions. More energetic, concert-appropriate.
// ═══════════════════════════════════════════════════════════════════════════════

/**
 * Blink — All Together
 * All LEDs flash on and off in unison.
 * 500ms on, 500ms off.
 */
void blinkAll(bool firstRun) {
  static uint32_t t      = 0;
  static bool     isOn   = false;

  if (firstRun) { isOn = false; t = millis(); allOff(); }

  if (wait(t, 500)) {
    t = millis();
    isOn = !isOn;
    isOn ? setAll(PWM_MAX) : allOff();
  }
}

/**
 * Blink — Alternate Green / White
 * Green groups and white groups flash alternately.
 * 350ms per group.
 */
void blinkAlternate(bool firstRun) {
  static uint32_t t        = 0;
  static bool     greenOn  = true;

  if (firstRun) { greenOn = true; t = millis(); allOff(); }

  if (wait(t, 350)) {
    t = millis();
    greenOn = !greenOn;
    setAllGreen(greenOn  ? PWM_MAX : 0);
    setAllWhite(!greenOn ? PWM_MAX : 0);
  }
}

/**
 * Blink — Heartbeat
 * Double-flash all LEDs: thump-thump ... long pause.
 * Timings: 80ms on, 100ms off, 80ms on, 900ms pause.
 */
void blinkHeartbeat(bool firstRun) {
  static uint32_t t    = 0;
  static uint8_t  step = 0;

  static const uint16_t dur[] = { 80, 100, 80, 900 };

  if (firstRun) { step = 0; t = millis(); allOff(); }

  if (wait(t, dur[step])) {
    t = millis();
    step = (step + 1) % 4;
    (step == 0 || step == 2) ? setAll(PWM_MAX) : allOff();
  }
}

/**
 * Blink — SOS
 * Morse code SOS on all LEDs (··· — — — ···).
 * Easter egg for concert emergencies.
 */
void blinkSOS(bool firstRun) {
  // Each pair: [on duration, off/gap duration] in ms
  // dot=180ms  dash=540ms  symbol gap=180ms  letter gap=540ms  word gap=1800ms
  static const uint16_t seq[] = {
    180, 180,    // S dot 1
    180, 180,    // S dot 2
    180, 540,    // S dot 3  + letter gap
    540, 180,    // O dash 1
    540, 180,    // O dash 2
    540, 540,    // O dash 3 + letter gap
    180, 180,    // S dot 1
    180, 180,    // S dot 2
    180, 1800,   // S dot 3  + word gap before repeat
  };
  static const uint8_t SEQ_LEN = sizeof(seq) / sizeof(seq[0]);

  static uint32_t t    = 0;
  static uint8_t  step = 0;

  if (firstRun) { step = 0; t = millis(); allOff(); }

  if (wait(t, seq[step])) {
    t = millis();
    step = (step + 1) % SEQ_LEN;
    (step % 2 == 0) ? setAll(PWM_MAX) : allOff();
  }
}

// ═══════════════════════════════════════════════════════════════════════════════
// PATTERN REGISTRY
// ─────────────────────────────────────────────────────────────────────────────
// Patterns cycle in the order listed here when the button is pressed.
// Group related patterns together using CAT_* labels for clarity.
// Add new patterns by appending a new { CAT_*, functionName, "Name" } line.
// ═══════════════════════════════════════════════════════════════════════════════

static const Pattern PATTERNS[] = {
  // ── WAVE ──────────────────────────────────────────────────────────────────
  { CAT_WAVE,   waveSlowCascade,  "Wave: Cascade"   },
  { CAT_WAVE,   wavePulseUp,      "Wave: Pulse Up"  },
  { CAT_WAVE,   waveRipple,       "Wave: Ripple"    },

  // ── BREATH ────────────────────────────────────────────────────────────────
  { CAT_BREATH, breathAll,        "Breath: All"     },
  { CAT_BREATH, breathCrossfade,  "Breath: Cross"   },
  { CAT_BREATH, breathTipFocus,   "Breath: Tip"     },

  // ── BLINK ─────────────────────────────────────────────────────────────────
  { CAT_BLINK,  blinkAll,         "Blink: All"      },
  { CAT_BLINK,  blinkAlternate,   "Blink: Alternate"},
  { CAT_BLINK,  blinkHeartbeat,   "Blink: Heartbeat"},
  { CAT_BLINK,  blinkSOS,         "Blink: SOS"      },
};

static const uint8_t NUM_PATTERNS = sizeof(PATTERNS) / sizeof(PATTERNS[0]);

// ═══════════════════════════════════════════════════════════════════════════════
// RUNTIME STATE
// ═══════════════════════════════════════════════════════════════════════════════

static uint8_t currentPattern  = 0;
static bool    patternFirstRun = true;

// ═══════════════════════════════════════════════════════════════════════════════
// BUTTON HANDLER
// ═══════════════════════════════════════════════════════════════════════════════

void handleButton() {
  if (digitalRead(PIN_BUTTON) != LOW) return;

  delay(DEBOUNCE_MS);
  if (digitalRead(PIN_BUTTON) != LOW) return;

  // Advance to next pattern
  currentPattern = (currentPattern + 1) % NUM_PATTERNS;

  // Persist to EEPROM — update() only writes if value changed (saves write cycles)
  EEPROM.update(EEPROM_PATTERN_ADDR, currentPattern);

  // Brief blackout so the user feels the pattern change
  allOff();
  delay(120);

  patternFirstRun = true;

  // Wait for button release before continuing
  while (digitalRead(PIN_BUTTON) == LOW) {}
  delay(DEBOUNCE_MS);
}

// ═══════════════════════════════════════════════════════════════════════════════
// SETUP & LOOP
// ═══════════════════════════════════════════════════════════════════════════════

void setup() {
  pinMode(PIN_TIP,          OUTPUT);
  pinMode(PIN_UPPER_STALK,  OUTPUT);
  pinMode(PIN_LOWER_STALK,  OUTPUT);
  pinMode(PIN_BASE,         OUTPUT);
  pinMode(PIN_BUTTON,       INPUT_PULLUP);

  allOff();

  // Restore last used pattern from EEPROM
  uint8_t saved = EEPROM.read(EEPROM_PATTERN_ADDR);
  if (saved < NUM_PATTERNS) {
    currentPattern = saved;
  } else {
    // EEPROM uninitialised (0xFF on fresh chip) — default to first pattern
    currentPattern = 0;
    EEPROM.write(EEPROM_PATTERN_ADDR, 0);
  }

  patternFirstRun = true;
}

void loop() {
  handleButton();
  PATTERNS[currentPattern].fn(patternFirstRun);
  patternFirstRun = false;
}

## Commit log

2026-03-10 hardware revision 1
    [BAT-SMD_MY-1220-03.step, BOM-HW-LEEK-001.csv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]
2026-03-17 HW Revision 02
    [BOM-HW-LEEK-001.csv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]
2026-05-17 Update final hardware
    [BAT-SMD_CR1220-2.step, BOM-HW-LEEK-001.csv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]
